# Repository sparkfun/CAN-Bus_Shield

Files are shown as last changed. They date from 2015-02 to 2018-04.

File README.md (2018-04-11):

SparkFun CAN-Bus Shield
==============

SparkFun CAN-BUS Shield

[*SparkFun CAN-BUS Shield (DEV-13262)*](https://www.sparkfun.com/products/13262)

This shield give the Arduino CAN-BUS capability. 

Repository Contents
-------------------

* **/Hardware** - Eagle design files (.brd, .sch)
* **/Libraries** - Libraries for use with the CAN-Bus Shield. 
* **/Production** - Production panel files (.brd)

Documentation
--------------
* **[Library](https://github.com/sparkfun/SparkFun_CAN-Bus_Arduino_Library)** - Arduino library for the CAN-Bus.
* **[Hookup Guide](https://learn.sparkfun.com/tutorials/can-bus-shield-hookup-guide)** - Basic hookup guide for the CAN-Bus.
* **[SparkFun Fritzing repo](https://github.com/sparkfun/Fritzing_Parts)** - Fritzing diagrams for SparkFun products.
* **[SparkFun 3D Model repo](https://github.com/sparkfun/3D_Models)** - 3D models of SparkFun products. 

Product Versions
----------------
* [DEV-13262](https://www.sparkfun.com/products/13262)- Version 1.3. Currently live. 
* [DEV-10039](https://www.sparkfun.com/products/retired/10039)- Version 1.2. Retired. 

GitHub Version History
---------------
* [V1.3](https://github.com/sparkfun/CAN-Bus_Shield/tree/v1.3) - This is version 1.3 of the shield. Currently live.
* [V1.2](https://github.com/sparkfun/CAN-Bus_Shield/tree/v1.2) - This is version 1.2 of the shield. Retired

License Information
-------------------

This product is _**open source**_! 

Please review the LICENSE.md file for license information. 

If you have any questions or concerns on licensing, please contact techsupport@sparkfun.com.

Distributed as-is; no warranty is given.

- Your friends at SparkFun.

This is a collaboration with SK Pang Electronics. A portion of each sale goes back to them for product support and continued development.

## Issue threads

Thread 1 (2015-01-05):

Fix page settings for schematic

ToniCorinne, 2015-01-05:
-Has the /1, /2 on pin flags

ToniCorinne, 2015-01-05:
Fixed.

Closed 2015-01-05.

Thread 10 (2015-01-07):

One 90 degree angle in bottom trace near DB9

SFE-KADE, 2015-01-07:

ToniCorinne, 2015-01-08:
Fixed.

Closed 2015-01-08.

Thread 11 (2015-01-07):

Test points on TX ann RX lines between ICs should use larger test point package

SFE-KADE, 2015-01-07:
The vias used for current test points are too small and the stop mask circles drawn on bottom layer are too small. Larger "3X5" test point package should work.

ToniCorinne, 2015-01-08:
Replaced. Question though - the QC check list says through-hole is preferable, so does the TP through-hole package need to be updated?

SFE-KADE, 2015-01-08:
The "through hole preferable" I believe refers to through hole header pads not a specific test point package in eagle. We should probably rethink the verbage in the checklist...

Closed 2015-01-08.

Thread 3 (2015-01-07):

Dashed grey lines needed to separate parts of sch

SFE-KADE, 2015-01-07:

ToniCorinne, 2015-01-08:
The schematic is separated by functionality sections  already(LCD, Arduino, uSD, CAN-Bus). I don't think it'd be great to split the CAN-Bus section down further, but if you can suggest a way that would make sense, I'm all ears.

SFE-KADE, 2015-01-08:
Good enough.

ToniCorinne, 2015-01-08:
Ok, closing this out then.

Closed 2015-01-08.

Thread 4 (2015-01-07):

PEDS1CAN IC ground pin not connected in sch/routed in brd

SFE-KADE, 2015-01-07:

ToniCorinne, 2015-01-08:
Fixed.

Closed 2015-01-08.

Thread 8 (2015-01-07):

VCC trace section not increased to new trace width.

SFE-KADE, 2015-01-07:
Small length near left via under large MCP IC

ToniCorinne, 2015-01-08:
Fixed.

Closed 2015-01-08.

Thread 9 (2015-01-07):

Ground pour not limited under hex converter and MCP2515 ICs

SFE-KADE, 2015-01-07:

ToniCorinne, 2015-01-08:
Fixed. Also limited under MCP2551.

Closed 2015-01-08.

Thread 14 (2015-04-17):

9-pin connector pinout

cjevans76, 2015-04-17:
Thanks for the work on this board - certainly worth a beer!  I'm just trying to get it to work and noticed that the pinout on the 9-way connector appears to be non-standard.  Every CAN bus I've ever worked with has this configuration:
pin 2: CAN-Low (CAN-)
pin 3: GND (Ground) - NOT ALWAYS USED
pin 7: CAN-High (CAN+)
pin 9: CAN V+ (Power) - NOT ALWAYS USED
I don't think there is anything in the ISO standard, but it's on the Wiki page for CAN so it must be true :)
It's not a huge issue - I can re-wire my 9-pin connector, but it does make the board harder to use with other CAN products (e.g. the ones from Kvaser, Softing, Vektor, ATI etc) which all use pins 2 & 7.  If the board ever does get re-spun it might be something to put on the to-do list.

ToniCorinne, 2015-06-16:
@cjevans76 we are actually working on a revision where this will be a configurable option. There are a lot of products that use both pinouts, so we want to make it available for as many users as possible.

Thanks for the feedback!

Closed 2015-06-16.

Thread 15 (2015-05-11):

Micro SD Card Socket

PatrickAlberts, 2015-05-11:
Hey Toni, this is pretty much my fault.  The updated micro sd footprint is the Micro SD 1:1

ToniCorinne, 2015-06-16:
Updated to the new one.

Closed 2015-06-16.

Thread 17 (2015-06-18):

version number needed in copper

SFE-KADE, 2015-06-18:

ToniCorinne, 2015-06-19:
Frame attribute strikes again. Fixed.

Closed 2015-06-19.

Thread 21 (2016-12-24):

Shield on Arduino Mega

Clamb94, 2016-12-24:
Hi, I'm trying to connect this shield to an Arduino Mega. Unfortunately it always result in a "Can't init CAN" message in the Serial monitor. I tried bending the SPI connectors (10-13) slightly to the side and connected wires from 50-53 on the Mega to 10-13 on the shield, but it still doesn't work. Any ideas?
Someone tried this before as succeeded, but probably with an other version of the lib, since I can't finde the file he mentioned anymore: http://forum.arduino.cc/index.php?topic=123367.0

Thank for the help. Best regards

Rahulelectobuddy, 2017-04-17:
with reference to : http://forum.arduino.cc/index.php?topic=123367.0 It was problem of library and nothing is related with sheild

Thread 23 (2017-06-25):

Can Bus Ecu Demo

Nish-Nando, 2017-06-25:
I"ve been trying to hook it up to my car it is giving me random weird values like 1 or 255 for Engine RPM and 191 or 255 for Vehicle speed. Any idea what maybe the source of error ?
@ToniCorinne

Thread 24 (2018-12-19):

Errors on Arduino Due but not other Arduino.  Canbus.cpp:16:20: fatal error: avr/io.h: No such file or directory

dookie454, 2018-12-19:
Help!!   I have two Sparkfun CanBus shields and both work great on Uno, nano, etc.   But when I try to compile on a Due, I get this error:

Canbus.cpp:16:20: fatal error: avr/io.h: No such file or directory

I've tried to narrow down what is causing the problem, but I cant.  All of the example code works for the Due,  plus a newer FASTLed library also works on Due after it was updated to work with Due, since it showed the same errors originally.    I dont know what changes were made though.

Thanks!

bboyho, 2020-05-28:
Hi,

I'm sorry for the delay in reply. The issue in the compile error for the Arduino Due is subtle.

    Canbus.cpp:16:20: fatal error: avr/io.h: No such file or directory

The part about the avr indicates that the library was written specifically for AVR microcontrollers. The Arduino Due uses a different architecture (specifically the SAMD). As a result, the library is not compatible unless you port the code for the SAMD architecture. This would probably require a preprocessor define, mapping pins, and ensuring any registers that may have been used for the library are compatible with the Arduino Due's SAMD.

I recommend simply sticking to the Arduino Uno and Nano that use an AVR microcontroller rather than using an ARM microcontroller.

Closed 2020-05-28.

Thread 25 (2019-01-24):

Was soll diese Zeile bezwecken?

jh-elec, 2019-01-24:
`	// load CNF1..3 Register
	RESET(MCP2515_CS);
	spi_putc(SPI_WRITE);
	spi_putc(CNF3);
/*	spi_putc((1<<PHSEG21));		// Bitrate 125 kbps at 16 MHz
	spi_putc((1<<BTLMODE)|(1<<PHSEG11));
	spi_putc((1<<BRP2)|(1<<BRP1)|(1<<BRP0));
*/
/*
	spi_putc((1<<PHSEG21));		// Bitrate 250 kbps at 16 MHz
	spi_putc((1<<BTLMODE)|(1<<PHSEG11));
	spi_putc((1<<BRP1)|(1<<BRP0));
*/
	spi_putc((1<<PHSEG21));		// Bitrate 250 kbps at 16 MHz
	spi_putc((1<<BTLMODE)|(1<<PHSEG11));
	//spi_putc(1<<BRP0);
        **spi_putc(speed);**`

"spi_putc(speed)" Was hat das Register was dort beschrieben wird mit Speed zu tun? Verstehe das nicht so ganz.. Das ist doch das Register für die Interrupts?!

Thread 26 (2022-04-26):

Terminating Resistor

adamoskaranikas, 2022-04-26:
Hi,

I just got my Shield delivered, and am trying to hook it up to an esp32, but with no success, aside from the obvious software meddling I need to do to get things going, I was also wondering if the shield has a 120ohm resistor between CANH and CANL already on the board, or if we are meant to place one externally if termination is needed. I've looked through the schematics and it doesn't seem that there is one in there, but I doubt that sparkfun did not consider the terminating resistor, so any pointers here would be much appreciated.

Thanks,
Adamos

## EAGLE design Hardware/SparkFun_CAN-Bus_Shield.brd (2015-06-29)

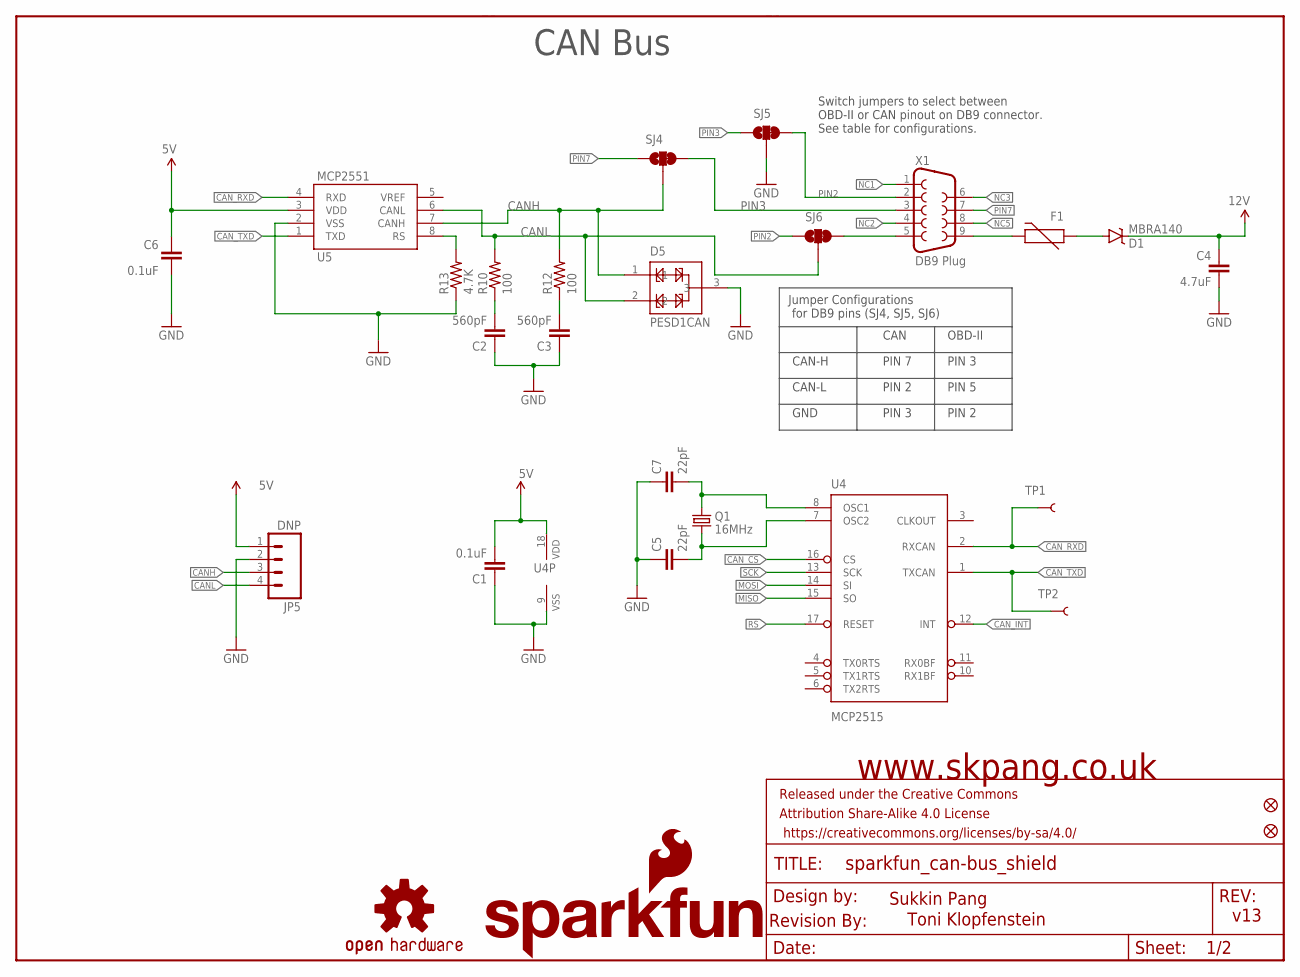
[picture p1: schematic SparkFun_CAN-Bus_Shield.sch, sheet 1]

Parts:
C1, C6: 0.1uF; 0603-CAP
C2, C3: 560pF; 0603-CAP
C4: 4.7uF; 0603-CAP
C5, C7: 22pF; 0603-CAP
D1: MBRA140; SMA-DIODE
D5: PESD1CAN; SOT23-3
F1: PTCTHERMISTOR1206; PTC-1206
FRAME1: FRAME-LETTER; CREATIVE_COMMONS
JP2, JP3: FIDUCIAL1X2; FIDUCIAL-1X2
JP4: SFE_LOGO_NAME_FLAME.1_INCH; SFE_LOGO_NAME_FLAME_.1
JP5: DNP; 1X04
LOGO1: OSHW-LOGOM; OSHW-LOGO-M
Q1: 16MHz; CRYSTAL-SMD-5X3
R10, R12: 100; 0603-RES
R13: 4.7K; 0603-RES
SJ4, SJ5, SJ6: JUMPER-PAD-3-2OF3_NC_BY_TRACE_SMALL; PAD-JUMPER-3-2OF3_NC_BY_TRACE_YES_SILK_FULL_BOX
TP1, TP2: TEST-POINT3X5; PAD.03X.05
U4: MCP2515; SO-18W
U5: MCP2551; SO08
U$1: REVISION
X1: DB9 Plug; DB9_MALE

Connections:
5V: C1.2, C6.2, JP5.1, U4.18 (VDD), U5.3 (VDD); also elsewhere on the board
12V: C4.1, D1.C; also elsewhere on the board
CANH: D5.1, JP5.3, R12.2, SJ4.2, U5.7 (CANH)
CANL: D5.2, JP5.4, R10.2, SJ6.2, U5.6 (CANL)
CAN_CS: U4.16 (CS); also elsewhere on the board
CAN_INT: U4.12 (INT); also elsewhere on the board
CAN_RXD: TP1.P$1, U4.2 (RXCAN), U5.4 (RXD)
CAN_TXD: TP2.P$1, U4.1 (TXCAN), U5.1 (TXD)
GND: C1.1, C2.1, C3.1, C4.2, C5.1, C6.1, C7.1, D5.3, JP5.2, R13.1, SJ5.2, U4.9 (VSS), U5.2 (VSS); also elsewhere on the board
MISO: U4.15 (SO); also elsewhere on the board
MOSI: U4.14 (SI); also elsewhere on the board
unnamed: SJ6.3, X1.5
unnamed: C2.2, R10.1
unnamed: C3.2, R12.1
unnamed: F1.2, X1.9
unnamed: R13.2, U5.8 (RS)
unnamed: D1.A, F1.1
unnamed: C7.2, Q1.3 (2), U4.8 (OSC1)
unnamed: C5.2, Q1.1, U4.7 (OSC2)
NC1: X1.1
NC2: X1.4
NC3: X1.6
NC5: X1.8
PIN2: SJ5.3, SJ6.1, X1.2
PIN3: SJ4.3, SJ5.1, X1.3
PIN7: SJ4.1, X1.7
RS: U4.17 (RESET); also elsewhere on the board
SCK: U4.13 (SCK); also elsewhere on the board

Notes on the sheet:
www.skpang.co.uk
Toni Klopfenstein
CAN Bus
CAN
OBD-II
CAN-H
CAN-L
GND
PIN 5
PIN 2
PIN 3
PIN 7
Jumper Configurations for DB9 pins (SJ4, SJ5, SJ6)
Switch jumpers to select between OBD-II or CAN pinout on DB9 connector. See table for configurations.
v13
Sukkin Pang

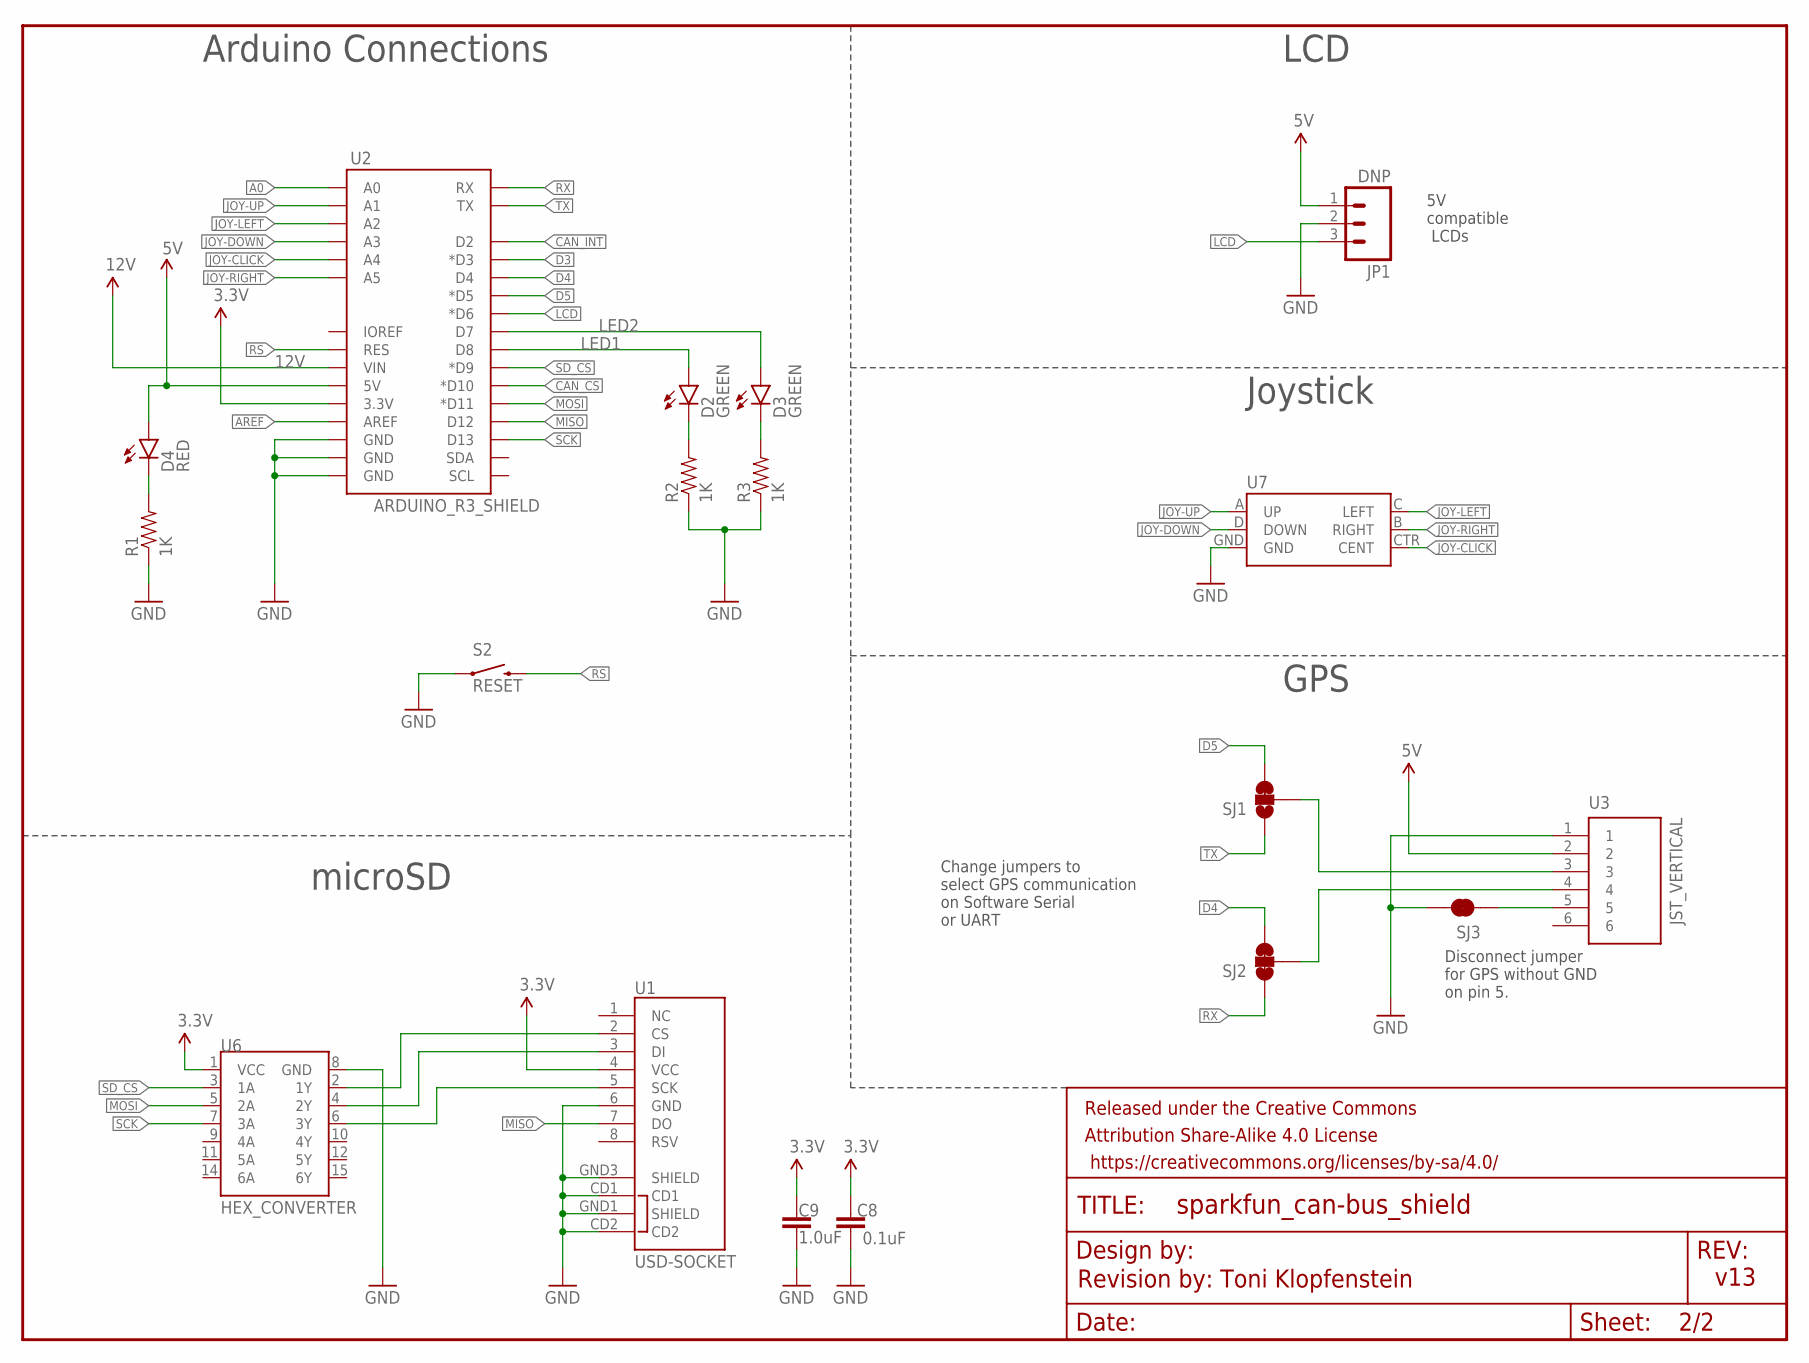
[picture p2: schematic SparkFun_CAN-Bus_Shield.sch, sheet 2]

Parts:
C8: 0.1uF; 0603-CAP
C9: 1.0uF; 0603-CAP
D2, D3: GREEN; LED-0603
D4: RED; LED-0603
FRAME2: FRAME-LETTERNO_PACKAGE; DUMMY
JP1: DNP; MOLEX-1X3_LOCK
R1, R2, R3: 1K; 0603-RES
S2: RESET; TACTILE-SWITCH-SMD
SJ1, SJ2: JUMPER-PAD-3-2OF3_NC_BY_TRACE_SMALL; PAD-JUMPER-3-2OF3_NC_BY_TRACE_YES_SILK_FULL_BOX
SJ3: JUMPER-PAD-2-NC_BY_TRACE; PAD-JUMPER-2-NC_BY_TRACE_YES_SILK
U1: USD-SOCKET; MICROSD_1:1
U2: ARDUINO_R3_SHIELD; UNO_R3_SHIELD
U3: JST_VERTICAL; JST-6-SMD-VERT-1.0MM
U6: HEX_CONVERTER; SO016
U7: JOYSTICK_MINI

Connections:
3.3V: C8.2, C9.1, U1.4 (VCC), U2.3.3V, U6.1 (VCC)
5V: D4.A, JP1.1, U2.5V, U3.2; also elsewhere on the board
12V: U2.VIN; also elsewhere on the board
A0: U2.A0
AREF: U2.AREF
CAN_CS: U2.D10 (*D10); also elsewhere on the board
CAN_INT: U2.D2; also elsewhere on the board
D3: U2.D3 (*D3)
D4: SJ2.3, U2.D4
D5: SJ1.3, U2.D5 (*D5)
GND: C8.1, C9.2, JP1.2, R1.1, R2.1, R3.1, S2.1, SJ3.2, U1.6 (GND), U1.CD1, U1.CD2, U1.GND1 (SHIELD), U1.GND3 (SHIELD), U2.GND@0 (GND), U2.GND@1 (GND), U2.GND@2 (GND), U3.1, U6.8 (GND), U7.GND; also elsewhere on the board
JOY-CLICK: U2.A4, U7.CTR (CENT)
JOY-DOWN: U2.A3, U7.D (DOWN)
JOY-LEFT: U2.A2, U7.C (LEFT)
JOY-RIGHT: U2.A5, U7.B (RIGHT)
JOY-UP: U2.A1, U7.A (UP)
LCD: JP1.3, U2.D6 (*D6)
LED1: D2.A, U2.D8
LED2: D3.A, U2.D7
MISO: U1.7 (DO), U2.D12; also elsewhere on the board
MOSI: U2.D11 (*D11), U6.5 (2A); also elsewhere on the board
unnamed: SJ3.1, U3.5
unnamed: D4.C, R1.2
unnamed: D2.C, R2.2
unnamed: D3.C, R3.2
unnamed: U1.2 (CS), U6.2 (1Y)
unnamed: U1.3 (DI), U6.4 (2Y)
unnamed: SJ1.2, U3.3
unnamed: SJ2.2, U3.4
unnamed: U1.5 (SCK), U6.6 (3Y)
RS: S2.3 (2), U2.RES; also elsewhere on the board
RX: SJ2.1, U2.RX
SCK: U2.D13, U6.7 (3A); also elsewhere on the board
SD_CS: U2.D9 (*D9), U6.3 (1A)
TX: SJ1.1, U2.TX

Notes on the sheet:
Arduino Connections
LCD
Joystick
5V compatible LCDs
GPS
Change jumpers to select GPS communication on Software Serial or UART
Disconnect jumper for GPS without GND on pin 5.
microSD
Revision by: Toni Klopfenstein
v13

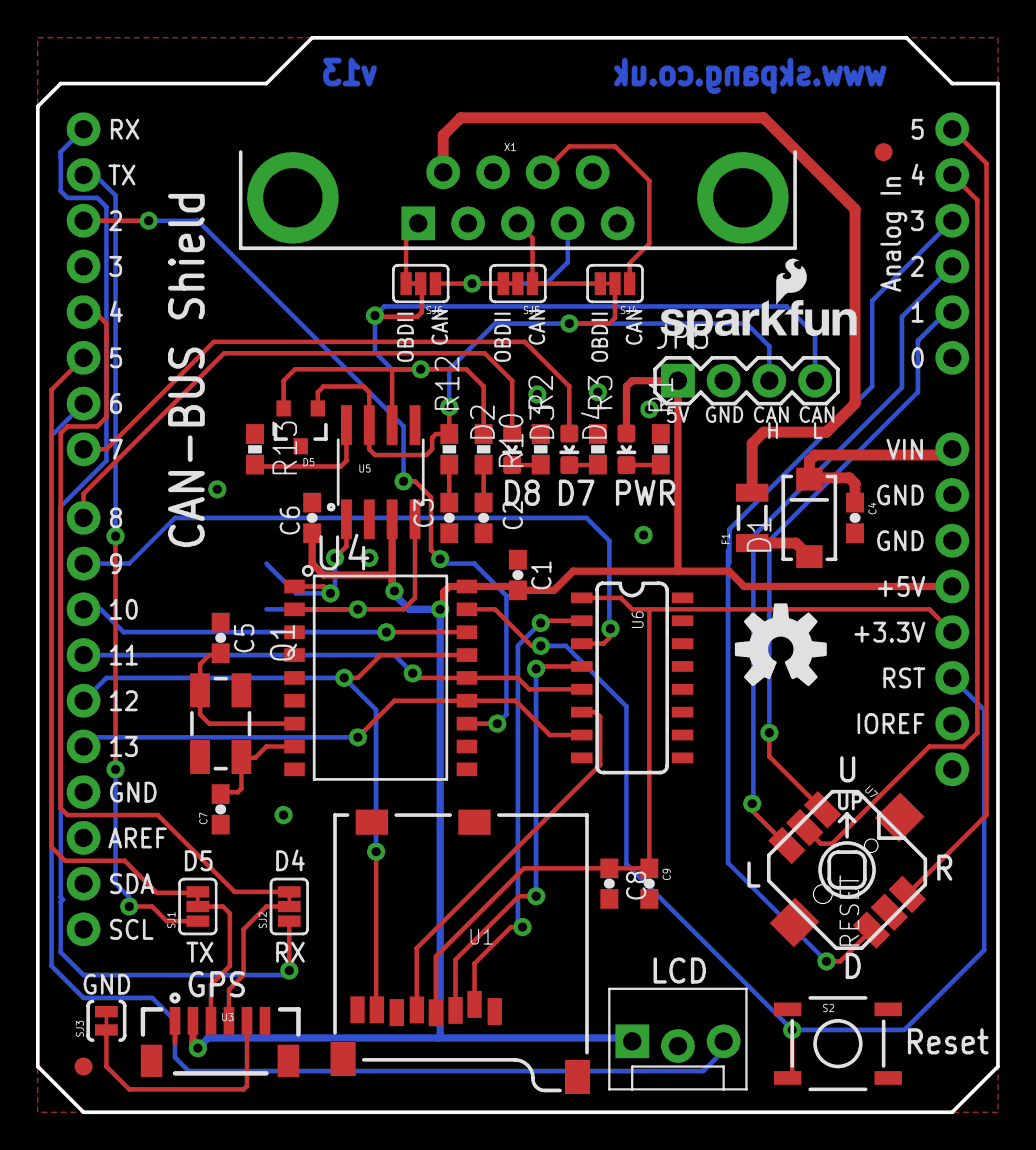
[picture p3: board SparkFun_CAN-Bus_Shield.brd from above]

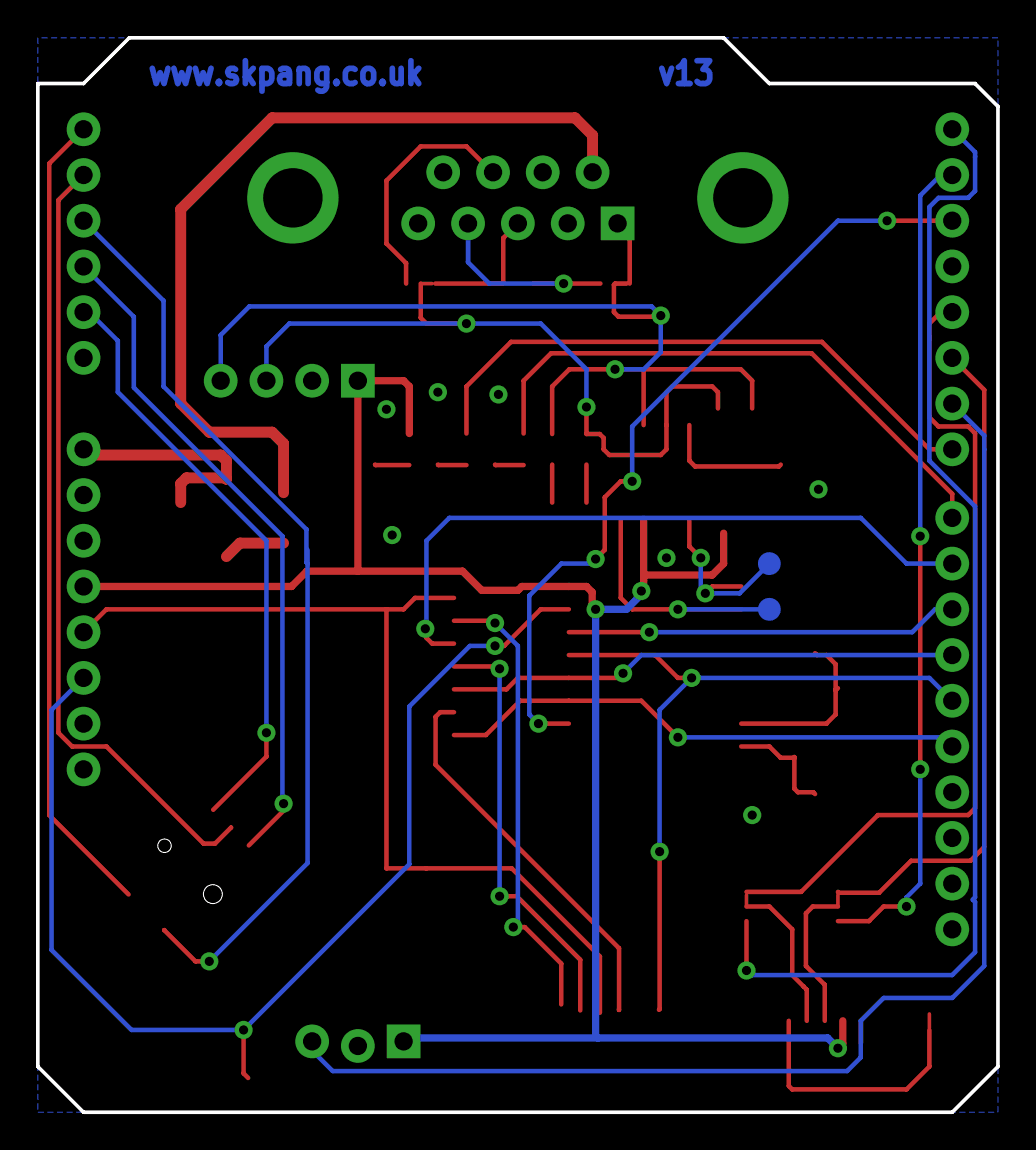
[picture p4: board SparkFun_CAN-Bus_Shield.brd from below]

Board: 2 copper layers, 53.3 x 59.7 mm, 48 parts (2 on the bottom side), 47 nets.

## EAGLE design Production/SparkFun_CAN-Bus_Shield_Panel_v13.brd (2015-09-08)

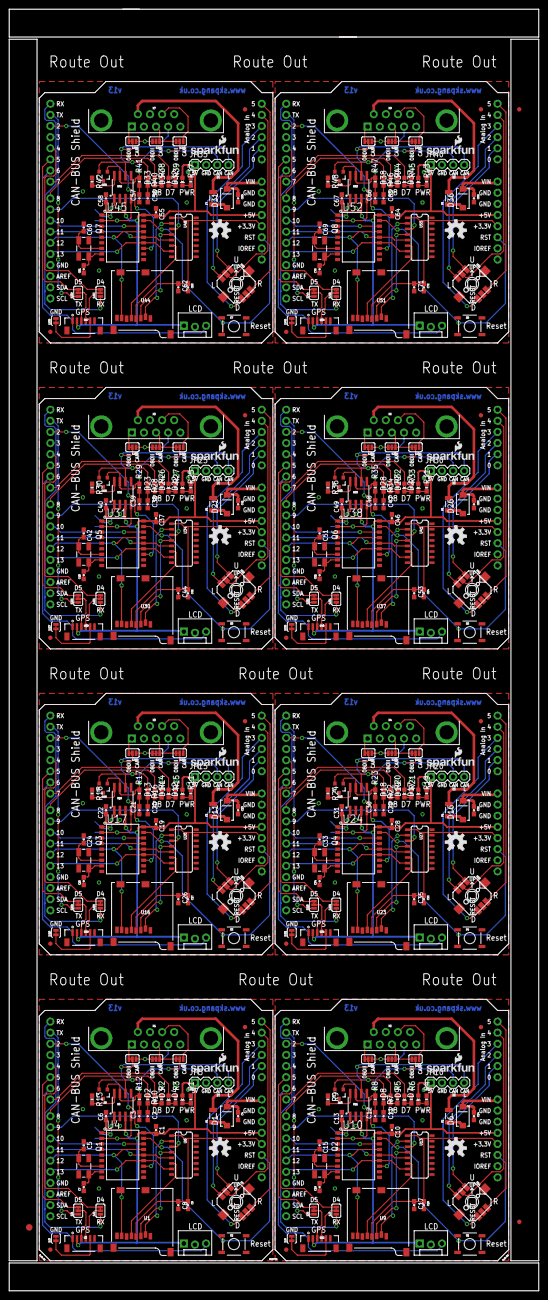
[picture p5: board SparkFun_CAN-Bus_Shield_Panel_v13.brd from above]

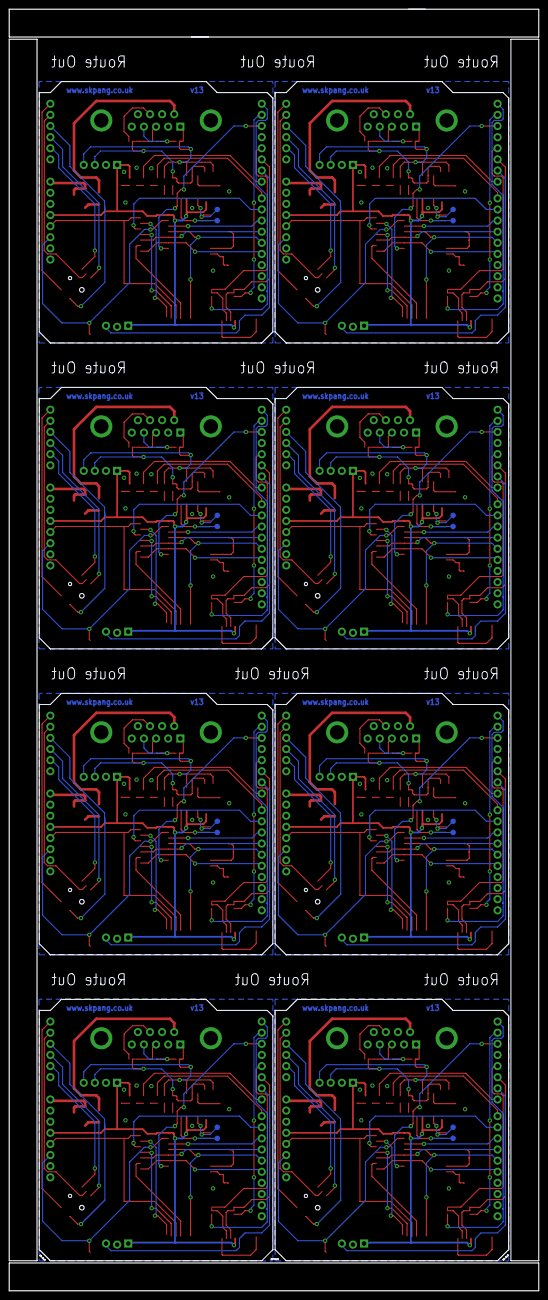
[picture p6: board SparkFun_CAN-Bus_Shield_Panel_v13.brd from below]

Board: 2 copper layers, 120.9 x 292.6 mm, 363 parts (16 on the bottom side), 376 nets.

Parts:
C1, C6, C8, C10, C13, C17, C19, C22, C26, C28, C31, C35, C37, C40, C44, C46, C49, C53, C55, C58, C62, C64, C67, C71: 0.1uF; 0603-CAP
C2, C3, C11, C12, C20, C21, C29, C30, C38, C39, C47, C48, C56, C57, C65, C66: 560pF; 0603-CAP
C4, C14, C23, C32, C41, C50, C59, C68: 4.7uF; 0603-CAP
C5, C7, C15, C16, C24, C25, C33, C34, C42, C43, C51, C52, C60, C61, C69, C70: 22pF; 0603-CAP
C9, C18, C27, C36, C45, C54, C63, C72: 1.0uF; 0603-CAP
D1, D6, D11, D16, D21, D26, D31, D36: MBRA140; SMA-DIODE
D2, D3, D8, D9, D13, D14, D18, D19, D23, D24, D28, D29, D33, D34, D38, D39: GREEN; LED-0603
D4, D7, D12, D17, D22, D27, D32, D37: RED; LED-0603
D5, D10, D15, D20, D25, D30, D35, D40: PESD1CAN; SOT23-3
E$1: FIDUCIAL-1.5X3
E$4, E$5: FIDUCIAL-1X2
F1, F2, F3, F4, F5, F6, F7, F8: PTC-1206
JP1, JP8, JP13, JP18, JP23, JP28, JP33, JP38: DNP; MOLEX-1X3_LOCK
JP2, JP3, JP6, JP7, JP11, JP12, JP16, JP17, JP21, JP22, JP26, JP27, JP31, JP32, JP36, JP37: FIDUCIAL1X2; FIDUCIAL-1X2
JP4, JP9, JP14, JP19, JP24, JP29, JP34, JP39: SFE_LOGO_NAME_FLAME.1_INCH; SFE_LOGO_NAME_FLAME_.1
JP5, JP10, JP15, JP20, JP25, JP30, JP35, JP40: DNP; 1X04
LOGO1, LOGO2, LOGO3, LOGO4, LOGO5, LOGO6, LOGO7, LOGO8: OSHW-LOGOM; OSHW-LOGO-M
Q1, Q2, Q3, Q4, Q5, Q6, Q7, Q8: 16MHz; CRYSTAL-SMD-5X3
R1, R2, R3, R4, R5, R6, R11, R14, R15, R19, R20, R21, R25, R26, R27, R31, R32, R33, R37, R38, R39, R43, R44, R45: 1K; 0603-RES
R7, R8, R10, R12, R16, R17, R22, R23, R28, R29, R34, R35, R40, R41, R46, R47: 100; 0603-RES
R9, R13, R18, R24, R30, R36, R42, R48: 4.7K; 0603-RES
S1, S2, S3, S4, S5, S6, S7, S8: RESET; TACTILE-SWITCH-SMD
SJ1, SJ2, SJ4, SJ5, SJ6, SJ7, SJ8, SJ10, SJ11, SJ12, SJ13, SJ14, SJ16, SJ17, SJ18, SJ19, SJ20, SJ22, SJ23, SJ24, SJ25, SJ26, SJ28, SJ29, SJ30, SJ31, SJ32, SJ34, SJ35, SJ36, SJ37, SJ38, SJ40, SJ41, SJ42, SJ43, SJ44, SJ46, SJ47, SJ48: JUMPER-PAD-3-2OF3_NC_BY_TRACE_SMALL; PAD-JUMPER-3-2OF3_NC_BY_TRACE_YES_SILK_FULL_BOX
SJ3, SJ9, SJ15, SJ21, SJ27, SJ33, SJ39, SJ45: JUMPER-PAD-2-NC_BY_TRACE; PAD-JUMPER-2-NC_BY_TRACE_YES_SILK
TP1, TP2, TP3, TP4, TP5, TP6, TP7, TP8, TP9, TP10, TP11, TP12, TP13, TP14, TP15, TP16: TEST-POINT3X5; PAD.03X.05
U1, U9, U16, U23, U30, U37, U44, U51: USD-SOCKET; MICROSD_1:1
U2, U8, U15, U22, U29, U36, U43, U50: ARDUINO_R3_SHIELD; UNO_R3_SHIELD
U3, U12, U19, U26, U33, U40, U47, U54: JST_VERTICAL; JST-6-SMD-VERT-1.0MM
U4, U10, U17, U24, U31, U38, U45, U52: MCP2515; SO-18W
U5, U11, U18, U25, U32, U39, U46, U53: MCP2551; SO08
U6, U13, U20, U27, U34, U41, U48, U55: HEX_CONVERTER; SO016
U7, U14, U21, U28, U35, U42, U49, U56: JOYSTICK_MINI
X1, X2, X3, X4, X5, X6, X7, X8: DB9 Plug; DB9_MALE

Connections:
3.3V: C8.2, C9.1, U1.4, U2.3.3V, U6.1
3.3V1: C17.2, C18.1, U8.3.3V, U9.4, U13.1
3.3V2: C26.2, C27.1, U15.3.3V, U16.4, U20.1
3.3V3: C35.2, C36.1, U22.3.3V, U23.4, U27.1
3.3V4: C44.2, C45.1, U29.3.3V, U30.4, U34.1
3.3V5: C53.2, C54.1, U36.3.3V, U37.4, U41.1
3.3V6: C62.2, C63.1, U43.3.3V, U44.4, U48.1
3.3V7: C71.2, C72.1, U50.3.3V, U51.4, U55.1
5V: C1.2, C6.2, D4.A, JP1.1, JP5.1, U2.5V, U3.2, U4.18, U5.3
5V1: C10.2, C13.2, D7.A, JP8.1, JP10.1, U8.5V, U10.18, U11.3, U12.2
5V2: C19.2, C22.2, D12.A, JP13.1, JP15.1, U15.5V, U17.18, U18.3, U19.2
5V3: C28.2, C31.2, D17.A, JP18.1, JP20.1, U22.5V, U24.18, U25.3, U26.2
5V4: C37.2, C40.2, D22.A, JP23.1, JP25.1, U29.5V, U31.18, U32.3, U33.2
5V5: C46.2, C49.2, D27.A, JP28.1, JP30.1, U36.5V, U38.18, U39.3, U40.2
5V6: C55.2, C58.2, D32.A, JP33.1, JP35.1, U43.5V, U45.18, U46.3, U47.2
5V7: C64.2, C67.2, D37.A, JP38.1, JP40.1, U50.5V, U52.18, U53.3, U54.2
12V: C4.1, D1.C, U2.VIN
12V1: C14.1, D6.C, U8.VIN
12V2: C23.1, D11.C, U15.VIN
12V3: C32.1, D16.C, U22.VIN
12V4: C41.1, D21.C, U29.VIN
12V5: C50.1, D26.C, U36.VIN
12V6: C59.1, D31.C, U43.VIN
12V7: C68.1, D36.C, U50.VIN
CANH: D5.1, JP5.3, R12.2, SJ4.2, U5.7
CANH1: D10.1, JP10.3, R8.2, SJ10.2, U11.7
CANH2: D15.1, JP15.3, R17.2, SJ16.2, U18.7
CANH3: D20.1, JP20.3, R23.2, SJ22.2, U25.7
CANH4: D25.1, JP25.3, R29.2, SJ28.2, U32.7
CANH5: D30.1, JP30.3, R35.2, SJ34.2, U39.7
CANH6: D35.1, JP35.3, R41.2, SJ40.2, U46.7
CANH7: D40.1, JP40.3, R47.2, SJ46.2, U53.7
CANL: D5.2, JP5.4, R10.2, SJ6.2, U5.6
CANL1: D10.2, JP10.4, R7.2, SJ12.2, U11.6
CANL2: D15.2, JP15.4, R16.2, SJ18.2, U18.6
CANL3: D20.2, JP20.4, R22.2, SJ24.2, U25.6
CANL4: D25.2, JP25.4, R28.2, SJ30.2, U32.6
CANL5: D30.2, JP30.4, R34.2, SJ36.2, U39.6
CANL6: D35.2, JP35.4, R40.2, SJ42.2, U46.6
CANL7: D40.2, JP40.4, R46.2, SJ48.2, U53.6
CAN_CS: U2.D10, U4.16
CAN_CS1: U8.D10, U10.16
CAN_CS2: U15.D10, U17.16
CAN_CS3: U22.D10, U24.16
CAN_CS4: U29.D10, U31.16
CAN_CS5: U36.D10, U38.16
CAN_CS6: U43.D10, U45.16
CAN_CS7: U50.D10, U52.16
CAN_INT: U2.D2, U4.12
CAN_INT1: U8.D2, U10.12
CAN_INT2: U15.D2, U17.12
CAN_INT3: U22.D2, U24.12
CAN_INT4: U29.D2, U31.12
CAN_INT5: U36.D2, U38.12
CAN_INT6: U43.D2, U45.12
CAN_INT7: U50.D2, U52.12
CAN_RXD: TP1.P$1, U4.2, U5.4
CAN_RXD1: TP3.P$1, U10.2, U11.4
CAN_RXD2: TP5.P$1, U17.2, U18.4
CAN_RXD3: TP7.P$1, U24.2, U25.4
CAN_RXD4: TP9.P$1, U31.2, U32.4
CAN_RXD5: TP11.P$1, U38.2, U39.4
CAN_RXD6: TP13.P$1, U45.2, U46.4
CAN_RXD7: TP15.P$1, U52.2, U53.4
CAN_TXD: TP2.P$1, U4.1, U5.1
CAN_TXD1: TP4.P$1, U10.1, U11.1
CAN_TXD2: TP6.P$1, U17.1, U18.1
CAN_TXD3: TP8.P$1, U24.1, U25.1
CAN_TXD4: TP10.P$1, U31.1, U32.1
CAN_TXD5: TP12.P$1, U38.1, U39.1
CAN_TXD6: TP14.P$1, U45.1, U46.1
CAN_TXD7: TP16.P$1, U52.1, U53.1
D1: SJ7.3, U8.D4
D2: SJ8.3, U8.D5
D4: SJ2.3, U2.D4
D5: SJ1.3, U2.D5
D7: SJ13.3, U15.D4
D8: SJ14.3, U15.D5
D10: SJ19.3, U22.D4
D11: SJ20.3, U22.D5
D13: SJ25.3, U29.D4
D14: SJ26.3, U29.D5
D16: SJ31.3, U36.D4
D17: SJ32.3, U36.D5
D19: SJ37.3, U43.D4
D20: SJ38.3, U43.D5
D22: SJ43.3, U50.D4
D23: SJ44.3, U50.D5
GND: C1.1, C2.1, C3.1, C4.2, C5.1, C6.1, C7.1, C8.1, C9.2, D5.3, JP1.2, JP5.2, R1.1, R2.1, R3.1, R13.1, S2.1, SJ3.2, SJ5.2, U1.6, U1.CD1, U1.CD2, U1.GND1, U1.GND3, U2.GND@0, U2.GND@1, U2.GND@2, U3.1, U4.9, U5.2, U6.8, U7.GND
GND1: C10.1, C11.1, C12.1, C13.1, C14.2, C15.1, C16.1, C17.1, C18.2, D10.3, JP8.2, JP10.2, R4.1, R5.1, R6.1, R9.1, S1.1, SJ9.2, SJ11.2, U8.GND@0, U8.GND@1, U8.GND@2, U9.6, U9.CD1, U9.CD2, U9.GND1, U9.GND3, U10.9, U11.2, U12.1, U13.8, U14.GND
GND2: C19.1, C20.1, C21.1, C22.1, C23.2, C24.1, C25.1, C26.1, C27.2, D15.3, JP13.2, JP15.2, R11.1, R14.1, R15.1, R18.1, S3.1, SJ15.2, SJ17.2, U15.GND@0, U15.GND@1, U15.GND@2, U16.6, U16.CD1, U16.CD2, U16.GND1, U16.GND3, U17.9, U18.2, U19.1, U20.8, U21.GND
GND3: C28.1, C29.1, C30.1, C31.1, C32.2, C33.1, C34.1, C35.1, C36.2, D20.3, JP18.2, JP20.2, R19.1, R20.1, R21.1, R24.1, S4.1, SJ21.2, SJ23.2, U22.GND@0, U22.GND@1, U22.GND@2, U23.6, U23.CD1, U23.CD2, U23.GND1, U23.GND3, U24.9, U25.2, U26.1, U27.8, U28.GND
GND4: C37.1, C38.1, C39.1, C40.1, C41.2, C42.1, C43.1, C44.1, C45.2, D25.3, JP23.2, JP25.2, R25.1, R26.1, R27.1, R30.1, S5.1, SJ27.2, SJ29.2, U29.GND@0, U29.GND@1, U29.GND@2, U30.6, U30.CD1, U30.CD2, U30.GND1, U30.GND3, U31.9, U32.2, U33.1, U34.8, U35.GND
GND5: C46.1, C47.1, C48.1, C49.1, C50.2, C51.1, C52.1, C53.1, C54.2, D30.3, JP28.2, JP30.2, R31.1, R32.1, R33.1, R36.1, S6.1, SJ33.2, SJ35.2, U36.GND@0, U36.GND@1, U36.GND@2, U37.6, U37.CD1, U37.CD2, U37.GND1, U37.GND3, U38.9, U39.2, U40.1, U41.8, U42.GND
GND6: C55.1, C56.1, C57.1, C58.1, C59.2, C60.1, C61.1, C62.1, C63.2, D35.3, JP33.2, JP35.2, R37.1, R38.1, R39.1, R42.1, S7.1, SJ39.2, SJ41.2, U43.GND@0, U43.GND@1, U43.GND@2, U44.6, U44.CD1, U44.CD2, U44.GND1, U44.GND3, U45.9, U46.2, U47.1, U48.8, U49.GND
GND7: C64.1, C65.1, C66.1, C67.1, C68.2, C69.1, C70.1, C71.1, C72.2, D40.3, JP38.2, JP40.2, R43.1, R44.1, R45.1, R48.1, S8.1, SJ45.2, SJ47.2, U50.GND@0, U50.GND@1, U50.GND@2, U51.6, U51.CD1, U51.CD2, U51.GND1, U51.GND3, U52.9, U53.2, U54.1, U55.8, U56.GND
JOY-CLICK: U2.A4, U7.CTR
JOY-CLICK1: U8.A4, U14.CTR
JOY-CLICK2: U15.A4, U21.CTR
JOY-CLICK3: U22.A4, U28.CTR
JOY-CLICK4: U29.A4, U35.CTR
JOY-CLICK5: U36.A4, U42.CTR
JOY-CLICK6: U43.A4, U49.CTR
JOY-CLICK7: U50.A4, U56.CTR
JOY-DOWN: U2.A3, U7.D
JOY-DOWN1: U8.A3, U14.D
JOY-DOWN2: U15.A3, U21.D
JOY-DOWN3: U22.A3, U28.D
JOY-DOWN4: U29.A3, U35.D
JOY-DOWN5: U36.A3, U42.D
JOY-DOWN6: U43.A3, U49.D
JOY-DOWN7: U50.A3, U56.D
JOY-LEFT: U2.A2, U7.C
JOY-LEFT1: U8.A2, U14.C
JOY-LEFT2: U15.A2, U21.C
JOY-LEFT3: U22.A2, U28.C
JOY-LEFT4: U29.A2, U35.C
JOY-LEFT5: U36.A2, U42.C
JOY-LEFT6: U43.A2, U49.C
JOY-LEFT7: U50.A2, U56.C
JOY-RIGHT: U2.A5, U7.B
JOY-RIGHT1: U8.A5, U14.B
JOY-RIGHT2: U15.A5, U21.B
JOY-RIGHT3: U22.A5, U28.B
JOY-RIGHT4: U29.A5, U35.B
JOY-RIGHT5: U36.A5, U42.B
JOY-RIGHT6: U43.A5, U49.B
JOY-RIGHT7: U50.A5, U56.B
JOY-UP: U2.A1, U7.A
JOY-UP1: U8.A1, U14.A
JOY-UP2: U15.A1, U21.A
JOY-UP3: U22.A1, U28.A
JOY-UP4: U29.A1, U35.A
JOY-UP5: U36.A1, U42.A
JOY-UP6: U43.A1, U49.A
JOY-UP7: U50.A1, U56.A
LCD: JP1.3, U2.D6
LCD1: JP8.3, U8.D6
LCD2: JP13.3, U15.D6
LCD3: JP18.3, U22.D6
LCD4: JP23.3, U29.D6
LCD5: JP28.3, U36.D6
LCD6: JP33.3, U43.D6
LCD7: JP38.3, U50.D6
LED1: D2.A, U2.D8
LED2: D3.A, U2.D7
LED3: D8.A, U8.D8
LED4: D9.A, U8.D7
LED5: D13.A, U15.D8
LED6: D14.A, U15.D7
LED7: D18.A, U22.D8
LED8: D19.A, U22.D7
LED9: D23.A, U29.D8
LED10: D24.A, U29.D7
LED11: D28.A, U36.D8
LED12: D29.A, U36.D7
LED13: D33.A, U43.D8
LED14: D34.A, U43.D7
LED15: D38.A, U50.D8
LED16: D39.A, U50.D7
MISO: U1.7, U2.D12, U4.15
MISO1: U8.D12, U9.7, U10.15
MISO2: U15.D12, U16.7, U17.15
MISO3: U22.D12, U23.7, U24.15
MISO4: U29.D12, U30.7, U31.15
MISO5: U36.D12, U37.7, U38.15
MISO6: U43.D12, U44.7, U45.15
MISO7: U50.D12, U51.7, U52.15
MOSI: U2.D11, U4.14, U6.5
MOSI1: U8.D11, U10.14, U13.5
MOSI2: U15.D11, U17.14, U20.5
MOSI3: U22.D11, U24.14, U27.5
MOSI4: U29.D11, U31.14, U34.5
MOSI5: U36.D11, U38.14, U41.5
MOSI6: U43.D11, U45.14, U48.5
MOSI7: U50.D11, U52.14, U55.5
unnamed: SJ3.1, U3.5
unnamed: SJ6.3, X1.5
unnamed: D8.C, R5.2
unnamed: D4.C, R1.2
unnamed: D2.C, R2.2
unnamed: D3.C, R3.2
unnamed: D9.C, R6.2
unnamed: C11.2, R7.1
unnamed: C2.2, R10.1
unnamed: C3.2, R12.1
unnamed: C12.2, R8.1
unnamed: R9.2, U11.8
unnamed: F1.2, X1.9
unnamed: R13.2, U5.8
unnamed: U1.2, U6.2
unnamed: D1.A, F1.1
unnamed: C7.2, Q1.3, U4.8
unnamed: C5.2, Q1.1, U4.7
unnamed: U1.3, U6.4
unnamed: F2.2, X2.9
unnamed: SJ1.2, U3.3
unnamed: SJ2.2, U3.4
unnamed: D6.A, F2.1
unnamed: U1.5, U6.6
unnamed: C16.2, Q2.3, U10.8
unnamed: C15.2, Q2.1, U10.7
unnamed: SJ8.2, U12.3
unnamed: SJ7.2, U12.4
unnamed: D7.C, R4.2
unnamed: U9.2, U13.2
unnamed: U9.3, U13.4
unnamed: U9.5, U13.6
unnamed: SJ9.1, U12.5
unnamed: SJ12.3, X2.5
unnamed: D13.C, R14.2
unnamed: D14.C, R15.2
unnamed: C20.2, R16.1
unnamed: C21.2, R17.1
unnamed: R18.2, U18.8
unnamed: F3.2, X3.9
unnamed: D11.A, F3.1
unnamed: C25.2, Q3.3, U17.8
unnamed: C24.2, Q3.1, U17.7
unnamed: SJ14.2, U19.3
unnamed: SJ13.2, U19.4
unnamed: D12.C, R11.2
unnamed: U16.2, U20.2
unnamed: U16.3, U20.4
unnamed: U16.5, U20.6
unnamed: SJ15.1, U19.5
unnamed: SJ18.3, X3.5
unnamed: D18.C, R20.2
unnamed: D19.C, R21.2
unnamed: C29.2, R22.1
unnamed: C30.2, R23.1
unnamed: R24.2, U25.8
unnamed: F4.2, X4.9
unnamed: D16.A, F4.1
unnamed: C34.2, Q4.3, U24.8
unnamed: C33.2, Q4.1, U24.7
unnamed: SJ20.2, U26.3
unnamed: SJ19.2, U26.4
unnamed: D17.C, R19.2
unnamed: U23.2, U27.2
unnamed: U23.3, U27.4
unnamed: U23.5, U27.6
unnamed: SJ21.1, U26.5
unnamed: SJ24.3, X4.5
unnamed: D23.C, R26.2
unnamed: D24.C, R27.2
unnamed: C38.2, R28.1
unnamed: C39.2, R29.1
unnamed: R30.2, U32.8
unnamed: F5.2, X5.9
unnamed: D21.A, F5.1
unnamed: C43.2, Q5.3, U31.8
unnamed: C42.2, Q5.1, U31.7
unnamed: SJ26.2, U33.3
unnamed: SJ25.2, U33.4
unnamed: D22.C, R25.2
unnamed: U30.2, U34.2
unnamed: U30.3, U34.4
unnamed: U30.5, U34.6
unnamed: SJ27.1, U33.5
unnamed: SJ30.3, X5.5
unnamed: D28.C, R32.2
unnamed: D29.C, R33.2
unnamed: C47.2, R34.1
unnamed: C48.2, R35.1
unnamed: R36.2, U39.8
unnamed: F6.2, X6.9
unnamed: D26.A, F6.1
unnamed: C52.2, Q6.3, U38.8
unnamed: C51.2, Q6.1, U38.7
unnamed: SJ32.2, U40.3
unnamed: SJ31.2, U40.4
unnamed: D27.C, R31.2
unnamed: U37.2, U41.2
unnamed: U37.3, U41.4
unnamed: U37.5, U41.6
unnamed: SJ33.1, U40.5
unnamed: SJ36.3, X6.5
unnamed: D33.C, R38.2
unnamed: D34.C, R39.2
unnamed: C56.2, R40.1
unnamed: C57.2, R41.1
unnamed: R42.2, U46.8
unnamed: F7.2, X7.9
unnamed: D31.A, F7.1
unnamed: C61.2, Q7.3, U45.8
unnamed: C60.2, Q7.1, U45.7
unnamed: SJ38.2, U47.3
unnamed: SJ37.2, U47.4
unnamed: D32.C, R37.2
unnamed: U44.2, U48.2
unnamed: U44.3, U48.4
unnamed: U44.5, U48.6
unnamed: SJ39.1, U47.5
unnamed: SJ42.3, X7.5
unnamed: D38.C, R44.2
unnamed: D39.C, R45.2
unnamed: C65.2, R46.1
unnamed: C66.2, R47.1
unnamed: R48.2, U53.8
unnamed: F8.2, X8.9
unnamed: D36.A, F8.1
unnamed: C70.2, Q8.3, U52.8
unnamed: C69.2, Q8.1, U52.7
unnamed: SJ44.2, U54.3
unnamed: SJ43.2, U54.4
unnamed: D37.C, R43.2
unnamed: U51.2, U55.2
unnamed: U51.3, U55.4
unnamed: U51.5, U55.6
unnamed: SJ45.1, U54.5
unnamed: SJ48.3, X8.5
PIN1: SJ10.3, SJ11.1, X2.3
PIN2: SJ5.3, SJ6.1, X1.2
PIN3: SJ4.3, SJ5.1, X1.3
PIN4: SJ10.1, X2.7
PIN5: SJ11.3, SJ12.1, X2.2
PIN6: SJ16.3, SJ17.1, X3.3
PIN7: SJ4.1, X1.7
PIN8: SJ16.1, X3.7
PIN9: SJ17.3, SJ18.1, X3.2
PIN10: SJ22.3, SJ23.1, X4.3
PIN11: SJ22.1, X4.7
PIN12: SJ23.3, SJ24.1, X4.2
PIN13: SJ28.3, SJ29.1, X5.3
PIN14: SJ28.1, X5.7
PIN15: SJ29.3, SJ30.1, X5.2
PIN16: SJ34.3, SJ35.1, X6.3
PIN17: SJ34.1, X6.7
PIN18: SJ35.3, SJ36.1, X6.2
PIN19: SJ40.3, SJ41.1, X7.3
PIN20: SJ40.1, X7.7
PIN21: SJ41.3, SJ42.1, X7.2
PIN22: SJ46.3, SJ47.1, X8.3
PIN23: SJ46.1, X8.7
PIN24: SJ47.3, SJ48.1, X8.2
RS: S2.3, U2.RES, U4.17
RS1: S1.3, U8.RES, U10.17
RS2: S3.3, U15.RES, U17.17
RS3: S4.3, U22.RES, U24.17
RS4: S5.3, U29.RES, U31.17
RS5: S6.3, U36.RES, U38.17
RS6: S7.3, U43.RES, U45.17
RS7: S8.3, U50.RES, U52.17
RX: SJ2.1, U2.RX
RX1: SJ7.1, U8.RX
RX2: SJ13.1, U15.RX
RX3: SJ19.1, U22.RX
RX4: SJ25.1, U29.RX
RX5: SJ31.1, U36.RX
RX6: SJ37.1, U43.RX
RX7: SJ43.1, U50.RX
SCK: U2.D13, U4.13, U6.7
SCK1: U8.D13, U10.13, U13.7
SCK2: U15.D13, U17.13, U20.7
SCK3: U22.D13, U24.13, U27.7
SCK4: U29.D13, U31.13, U34.7
SCK5: U36.D13, U38.13, U41.7
SCK6: U43.D13, U45.13, U48.7
SCK7: U50.D13, U52.13, U55.7
SD_CS: U2.D9, U6.3
SD_CS1: U8.D9, U13.3
SD_CS2: U15.D9, U20.3
SD_CS3: U22.D9, U27.3
SD_CS4: U29.D9, U34.3
SD_CS5: U36.D9, U41.3
SD_CS6: U43.D9, U48.3
SD_CS7: U50.D9, U55.3
TX: SJ1.1, U2.TX
TX1: SJ8.1, U8.TX
TX2: SJ14.1, U15.TX
TX3: SJ20.1, U22.TX
TX4: SJ26.1, U29.TX
TX5: SJ32.1, U36.TX
TX6: SJ38.1, U43.TX
TX7: SJ44.1, U50.TX

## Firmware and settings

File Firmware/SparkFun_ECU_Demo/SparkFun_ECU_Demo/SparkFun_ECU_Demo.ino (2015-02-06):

/****************************************************************************
ECU CAN-Bus Reader and Logger

Toni Klopfenstein @ SparkFun Electronics
February 2015
https://github.com/sparkfun/CAN-Bus_Shield

This example sketch works with the CAN-Bus shield from SparkFun Electronics.

It enables reading of the MCP2515 CAN controller and MCP2551 CAN-Bus driver.
This sketch also enables logging of GPS data, and output to a serial-enabled LCD screen.
All data is logged to the uSD card. 

Resources:
Additional libraries to install for functionality of sketch.
-SD library by William Greiman. https://github.com/greiman/SdFat 
 
Development environment specifics:
Developed for Arduino 1.05

Based off of original example ecu_reader_logger by:
Sukkin Pang
SK Pang Electronics www.skpang.co.uk

This code is beerware; if you see me (or any other SparkFun employee) at the local, and you've found our code helpful, please buy us a round!
Distributed as-is; no warranty is given.
*************************************************************************/

//Include necessary libraries for compilation
#include <SD.h>
#include <SoftwareSerial.h>
#include <Canbus.h>
#include <TinyGPS.h>

//Initialize uSD pins
const int chipSelect = 9;

//Initialize lcd pins
SoftwareSerial lcd(3, 6);

//Initialize GPS pins
SoftwareSerial uart_gps(4,5);

// Define Joystick connection pins 
#define UP     A1
#define DOWN   A3
#define LEFT   A2
#define RIGHT  A5
#define CLICK  A4

//Define LED pins
#define LED2 8
#define LED3 7

//Define baud rates. GPS should be slower than serial to ensure valid sentences coming through
#define rate 115200;
#define GPS_Rate 4800;
#define LCD_Rate 115200;

//Create instance of TinyGPS
TinyGPS gps;

//Declare porototype for TinyGPS library functions
void getgps(TinyGPS &gps);

char buffer[512];

//Define LCD Positions
#define COMMAND 0xFE
#define CLEAR   0x01
#define LINE1  0x80
#define LINE2  0xC0


//********************************Setup Loop*********************************//
void setup() {
  //Initialize Serial communication for debugging
  Serial.begin(rate);
  Serial.println("ECU Demo");
  
  //Begin LCD serial communication
  lcd.begin(LCD_Rate);
  
  //Begin GPS communcation
  uart_gps.begin(GPS_Rate);
  
  //Initialize pins as necessary
  pinMode(chipSelect, OUTPUT);
  pinMode(UP,INPUT);
  pinMode(DOWN,INPUT);
  pinMode(LEFT,INPUT);
  pinMode(RIGHT,INPUT);
  pinMode(CLICK,INPUT);
  pinMode(LED2, OUTPUT);
  pinMode(LED3, OUTPUT);
  
  //Pull analog pins high to enable reading of joystick movements
  digitalWrite(UP, HIGH);
  digitalWrite(DOWN, HIGH);
  digitalWrite(LEFT, HIGH);
  digitalWrite(RIGHT, HIGH);
  digitalWrite(CLICK, HIGH);
  
  //Write LED pins low to turn them off by default
  digitalWrite(LED2, LOW);
  digitalWrite(LED3, LOW);
  
  //Check if uSD card initialized
  if (!SD.begin(chipSelect)) {
    Serial.println("uSD card failed to initialize, or is not present");
    return;
  }
  else{
      Serial.println("uSD card initialized.");
  } 
  
  //Print menu to LCD screen
  clear_lcd();
  lcd.print("Click to begin");
  lcd.write(COMMAND);
  lcd.write(LINE2);
  lcd.print("Logging Data");
  

}

//********************************Main Loop*********************************//
void loop(){
  
  File dataFile = SD.open("ECU_datalog.txt", FILE_WRITE);
  
  //If data file exists, write data to it
  if (dataFile){
    
    clear_lcd();
    lcd.print("Logging data");
    clear_lcd();
    lcd.print("Click joystick");
    lcd.write(COMMAND);
    lcd.write(LINE2);
    lcd.print("to stop logging");
    
    if(uart_gps.available())     // While there is data on the RX pin...
       {
         int c = uart_gps.read();    // load the data into a variable...
         if(gps.encode(c))      // if there is a new valid sentence...
         {
           getgps(gps);         // then grab the data.
         }
       }
     
    get_CAN(); //grab CAN data
     
    
    dataFile.println();
    dataFile.close();   //Close data logging file
  }
  //If file cannot be opened,write error to LCD screen
  else{
    clear_lcd();
    lcd.print("Error opening");
    lcd.write(COMMAND);
    lcd.write(LINE2);
    lcd.print("ECU_datalog.txt");
  }
  
}
//********************************CAN Bus Functions*********************************//

void get_CAN(void)
{
  Canbus.ecu_req(ENGINE_RPM,buffer); //Request engine RPM
  dataFile.print("Engine RPM: "); 
  dataFile.println(buffer);
  
  Canbus.ecu_req(VEHICLE_SPEED,buffer); //Request Vehicle speed
  dataFile.print("Vehicle speed: "); 
  dataFile.println(buffer);
  
  Canbus.ecu_req(ENGINE_COOLANT_TEMP,buffer); //Request engine coolant temp
  dataFile.print("Coolant temp: "); 
  dataFile.println(buffer);
  
  Canbus.ecu_req(THROTTLE, buffer); //Request throttle
  dataFile.print("Throttle: "); 
  dataFile.println(buffer);
 
  
}
//********************************LCD Functions*********************************//
void clear_lcd(void)
{
  lcd.write(COMMAND);
  lcd.write(CLEAR);
} 

//********************************GPS Functions*********************************//
void getgps(TinyGPS &gps)
{
  
  // Define the variables that will be used
  float latitude, longitude;
  // Then call this function
  gps.f_get_position(&latitude, &longitude);
  // You can now print variables latitude and longitude
  dataFile.print("Lat/Long: "); 
  dataFile.print(latitude,5); 
  dataFile.print(", "); 
  dataFile.println(longitude,5);
  
  // Same goes for date and time
  int year;
  byte month, day, hour, minute, second, hundredths;
  gps.crack_datetime(&year,&month,&day,&hour,&minute,&second,&hundredths);
  // Print data and time
  dataFile.print("Date: "); dataFile.print(month, DEC); dataFile.print("/"); 
  dataFile.print(day, DEC); dataFile.print("/"); dataFile.print(year);
  dataFile.print("  Time: "); dataFile.print(hour, DEC); dataFile.print(":"); 
  dataFile.print(minute, DEC); dataFile.print(":"); dataFile.print(second, DEC); 
  dataFile.print("."); dataFile.println(hundredths, DEC);
  //Since month, day, hour, minute, second, and hundr
  
  // Here you can print the altitude and course values directly since 
  // there is only one value for the function
  dataFile.print("Altitude(m): "); dataFile.println(gps.f_altitude());  
  // Same goes for course
  dataFile.print("Course(deg): "); dataFile.println(gps.f_course()); 
  // And same goes for speed
  dataFile.print("GPS Speed(kmph): "); dataFile.println(gps.f_speed_kmph());
  dataFile.println();
}

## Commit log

2013-11-19 Initial commit of board files and README
    [CAN-Bus_Shield.brd, CAN-Bus_Shield.sch]
2013-11-25 Updating Board files to R3/Leonardo layout
    [CAN-Bus_Shield.brd, CAN-Bus_Shield.sch]
2014-05-22 Fixing traces
    [CAN-Bus_Shield.brd]
2014-11-26 Midway changes for rev
    [CAN-Bus_Shield.brd, CAN-Bus_Shield.sch, SparkFun_CAN-Bus_Shield.brd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]
2014-12-23 Schematic updates for QC checklist
    [SparkFun_CAN-Bus_Shield.brd, SparkFun_CAN-Bus_Shield.sch]
2014-12-31 Adding in OBDII/CAN jumpers
    [SparkFun_CAN-Bus_Shield.brd, SparkFun_CAN-Bus_Shield.sch]
2015-01-03 Adding ESD protection to CAN lines
    [SparkFun_CAN-Bus_Shield.brd, SparkFun_CAN-Bus_Shield.sch]
2015-01-05 Adding in feedback from Sukkin, and engineering review/QC checklist
    [SparkFun_CAN-Bus_Shield.brd, SparkFun_CAN-Bus_Shield.sch]
2015-01-05 Fixing DRC errors
    [SparkFun_CAN-Bus_Shield.brd]
2015-01-08 Pushing QC checklist changes
    [SparkFun_CAN-Bus_Shield.brd, SparkFun_CAN-Bus_Shield.sch]
2015-01-08 Fixing test points
    [SparkFun_CAN-Bus_Shield.brd]
2015-04-09 Added production directory, updating shield units to pass QC check
    [SparkFun_CAN-Bus_Shield.brd, SparkFun_CAN-Bus_Shield.sch]
2015-06-16 Updating to new uSD footprint, minor QC cleanup on schematic
    [SparkFun_CAN-Bus_Shield.brd, SparkFun_CAN-Bus_Shield.sch]
2015-06-19 Fixing QC checks
    [SparkFun_CAN-Bus_Shield.brd]
2015-06-29 Updating PESD1CAN part to new library path
    [SparkFun_CAN-Bus_Shield.brd, SparkFun_CAN-Bus_Shield.sch]
2015-07-01 created panel v13
    [SparkFun_CAN-Bus_Shield_Panel_v13.brd]
2015-09-08 Adding Demo sketch-WIP
    [SparkFun_CAN-Bus_Shield.sch]
2015-10-14 Squashed 'Libraries/Arduino/' content from commit 1487658
    git-subtree-dir: Libraries/Arduino
    git-subtree-split: 1487658099556a8c6ec7d1cb3a7c75e15ad34a6e
2016-03-15 Squashed 'Libraries/Arduino/' changes from 1487658..ffcd67b
    ffcd67b Fixing image URL
    939f654 @PlatformIO Library Registry manifest file
    git-subtree-split: ffcd67b7f4d5112f747f7c74a8677ef82a4ee202
    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
2017-01-18 Squashed 'Libraries/Arduino/' changes from ffcd67b..99644e8
    99644e8 Adding additional demo sketches and updating library version
    git-subtree-split: 99644e84e184ecb8240c22ee06ea4a4871b766ba
    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

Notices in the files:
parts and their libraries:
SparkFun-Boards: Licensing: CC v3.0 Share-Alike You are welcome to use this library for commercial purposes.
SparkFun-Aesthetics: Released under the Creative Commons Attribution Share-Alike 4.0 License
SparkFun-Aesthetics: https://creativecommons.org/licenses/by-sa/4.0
